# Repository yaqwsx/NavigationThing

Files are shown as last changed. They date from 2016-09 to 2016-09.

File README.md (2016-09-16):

# NavigationThing

The thing, which will safely guide you through darkness. A prop used during
[K-SCUK 2016](http://kscuk.fi.muni.cz/) night game.

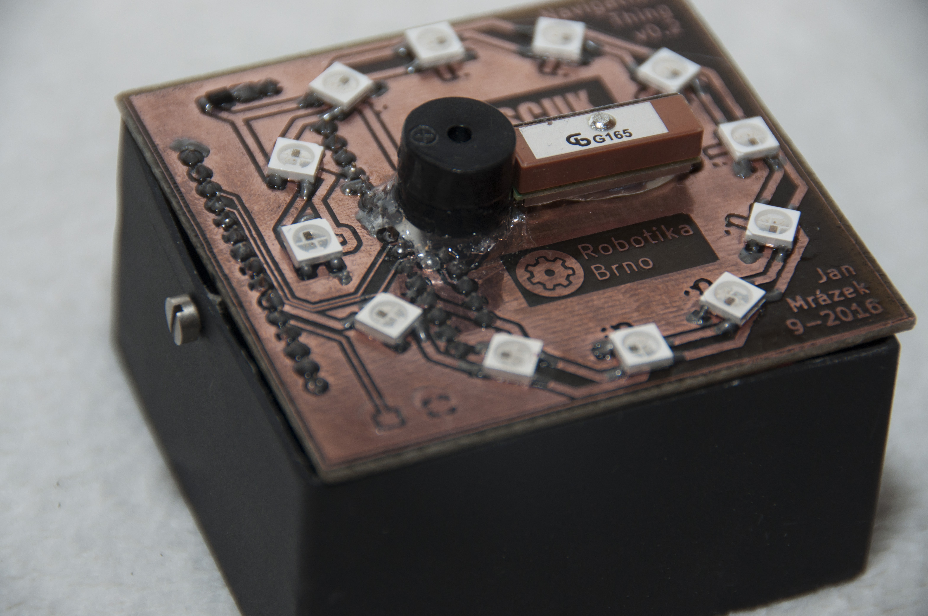
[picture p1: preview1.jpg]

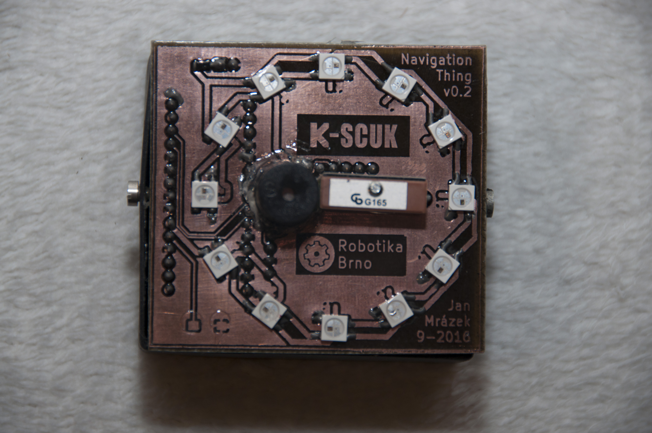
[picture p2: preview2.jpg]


# What does it do?

NavigationThing features an electronic compass and a GPS receiver, which are
used for navigation of a user through a series of waypoints. Distance to the
next waypoint is indicated via beeping, which adds a mysterious feeling. Closer
the user is, the faster the box beeps. NavigationThing is powered by 4 AA
batteries.

# How to use it?

The navigation thing is ready out of box. When you power it for the first time,
the unit beeps, goes black for 3 seconds and then the unit enters compass
calibration mode, which is indited via purple flashing. **It is necessary to
rotate the unit on a flat surface until it stops flashing.** After initial setup,
the unit starts normal operation.

During normal operation, the thing shows either electronic compass or flashes
red. Red flashing indicates missing GPS fix. The thing remembers progress in
EEPROM, so user can safely remove batteries in the middle of operation and
insert them back again. To reset the unit, simply short two pads in the left-
bottom corner of PCB during power-up. Then restart the unit.

To change waypoints, change `waypoints` array in the firmware source code. When
user enters a waypoint, an user supplied callback function is called.

# Repository Structure

The repository is organized as follow:

- `NavigationThing` contains the unit's firmware. The firmware is written in
  Arduino to keep things simple.

- `NavigationThingHwTest` contains testing firmware, which tests the PCB - LEDs
  and peripherals communication.

- `hw` contains schematics and PCBs in KiCAD

I am sorry, there are no CAD files for the box.

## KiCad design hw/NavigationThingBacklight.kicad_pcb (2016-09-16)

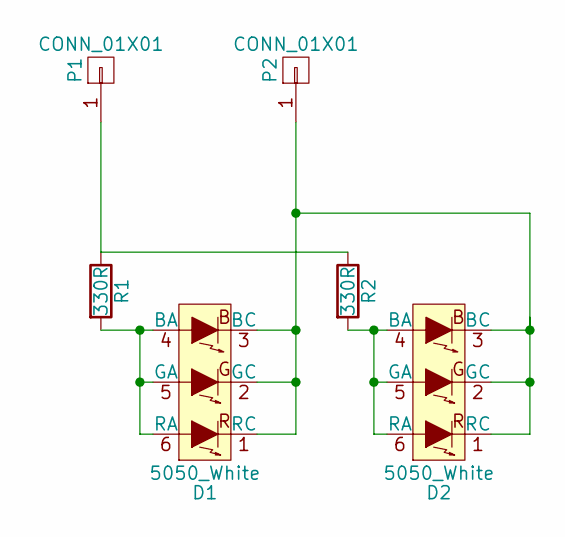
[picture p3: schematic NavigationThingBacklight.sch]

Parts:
D1, D2: 5050_White; LED_RGB_PLLC-6
P1, P2: CONN_01X01; SolderWirePad_single_SMD_5x10mm
R1, R2: 330R; R_0603_HandSoldering

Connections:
unnamed: D1.1 (RC), D1.2 (GC), D1.3 (BC), D2.1 (RC), D2.2 (GC), D2.3 (BC), P2.1
unnamed: D1.4 (BA), D1.5 (GA), D1.6 (RA), R1.2
unnamed: D2.4 (BA), D2.5 (GA), D2.6 (RA), R2.2
unnamed: P1.1, R1.1, R2.1

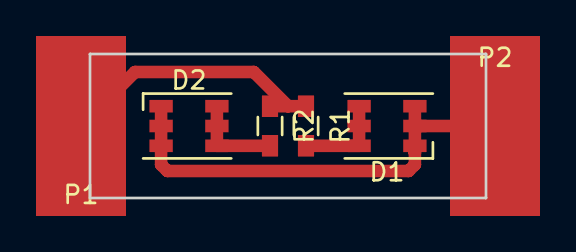
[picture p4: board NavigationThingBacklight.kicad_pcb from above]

Board: 2 copper layers, 22.0 x 8.0 mm, 6 parts (0 on the bottom side), 4 nets.

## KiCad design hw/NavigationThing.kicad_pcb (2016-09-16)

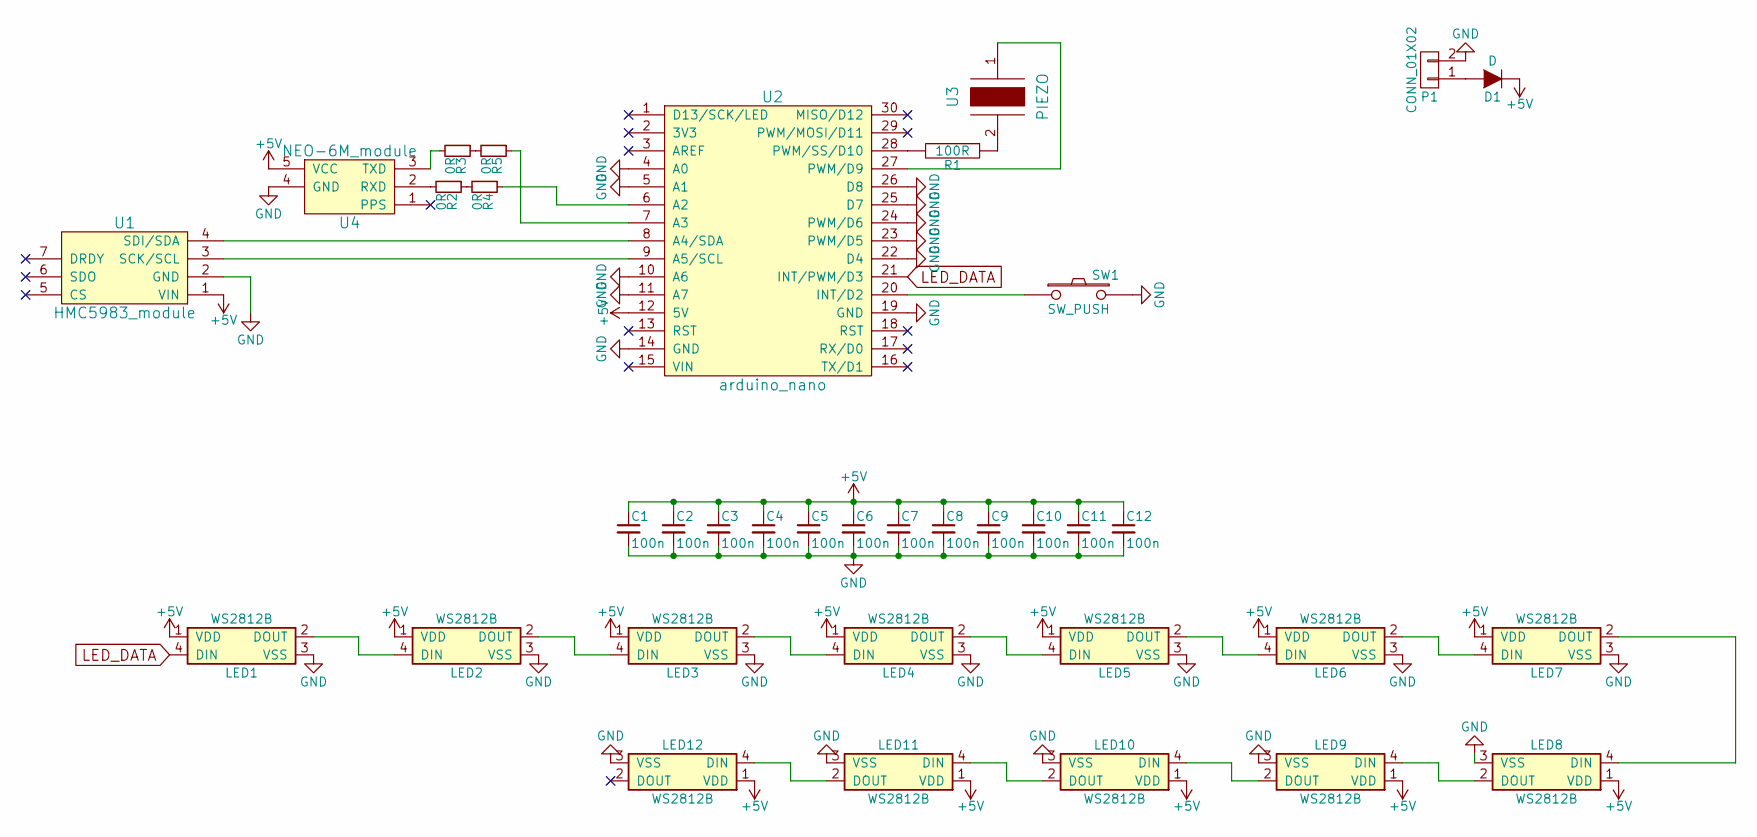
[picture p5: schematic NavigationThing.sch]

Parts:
C1, C2, C3, C4, C5, C6, C7, C8, C9, C10, C11, C12: 100n; C_0603
D1: D; SOD-323
LED1, LED2, LED3, LED4, LED5, LED6, LED7, LED8, LED9, LED10, LED11, LED12: WS2812B; LED_WS2812B-PLCC4
P1: CONN_01X02; Pin_Header_Straight_1x02
R1: 100R; R_0603_HandSoldering
R2, R3, R4, R5: 0R; R_0603_HandSoldering
SW1: SW_PUSH; SW_SPST_EVQPE1
U1: HMC5983_module
U2: arduino_nano
U3: PIEZO; piezo_12
U4: NEO-6M_module

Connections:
+5V: C1.1, C2.1, C3.1, C4.1, C5.1, C6.1, C7.1, C8.1, C9.1, C10.1, C11.1, C12.1, D1.1 (K), LED1.1 (VDD), LED2.1 (VDD), LED3.1 (VDD), LED4.1 (VDD), LED5.1 (VDD), LED6.1 (VDD), LED7.1 (VDD), LED8.1 (VDD), LED9.1 (VDD), LED10.1 (VDD), LED11.1 (VDD), LED12.1 (VDD), U1.1 (VIN), U2.12 (5V), U4.5 (VCC)
GND: C1.2, C2.2, C3.2, C4.2, C5.2, C6.2, C7.2, C8.2, C9.2, C10.2, C11.2, C12.2, LED1.3 (VSS), LED2.3 (VSS), LED3.3 (VSS), LED4.3 (VSS), LED5.3 (VSS), LED6.3 (VSS), LED7.3 (VSS), LED8.3 (VSS), LED9.3 (VSS), LED10.3 (VSS), LED11.3 (VSS), LED12.3 (VSS), P1.2, SW1.2, U1.2 (GND), U2.4 (A0), U2.5 (A1), U2.10 (A6), U2.11 (A7), U2.14 (GND), U2.19 (GND), U2.22 (D4), U2.23 (PWM/D5), U2.24 (PWM/D6), U2.25 (D7), U2.26 (D8), U4.4 (GND)
LED_DATA: LED1.4 (DIN), U2.21 (INT/PWM/D3)
unnamed: D1.2 (A), P1.1
unnamed: LED1.2 (DOUT), LED2.4 (DIN)
unnamed: LED2.2 (DOUT), LED3.4 (DIN)
unnamed: LED3.2 (DOUT), LED4.4 (DIN)
unnamed: LED4.2 (DOUT), LED5.4 (DIN)
unnamed: LED5.2 (DOUT), LED6.4 (DIN)
unnamed: LED6.2 (DOUT), LED7.4 (DIN)
unnamed: LED7.2 (DOUT), LED8.4 (DIN)
unnamed: LED8.2 (DOUT), LED9.4 (DIN)
unnamed: LED10.2 (DOUT), LED11.4 (DIN)
unnamed: LED9.2 (DOUT), LED10.4 (DIN)
unnamed: LED11.2 (DOUT), LED12.4 (DIN)
unnamed: R1.1, U3.2
unnamed: R1.2, U2.28 (PWM/SS/D10)
unnamed: R2.1, R4.2
unnamed: R2.2, U4.2 (RXD)
unnamed: R3.1, R5.2
unnamed: R3.2, U4.3 (TXD)
unnamed: R4.1, U2.6 (A2)
unnamed: R5.1, U2.7 (A3)
unnamed: SW1.1, U2.20 (INT/D2)
unnamed: U1.3 (SCK/SCL), U2.9 (A5/SCL)
unnamed: U1.4 (SDI/SDA), U2.8 (A4/SDA)
unnamed: U2.27 (PWM/D9), U3.1

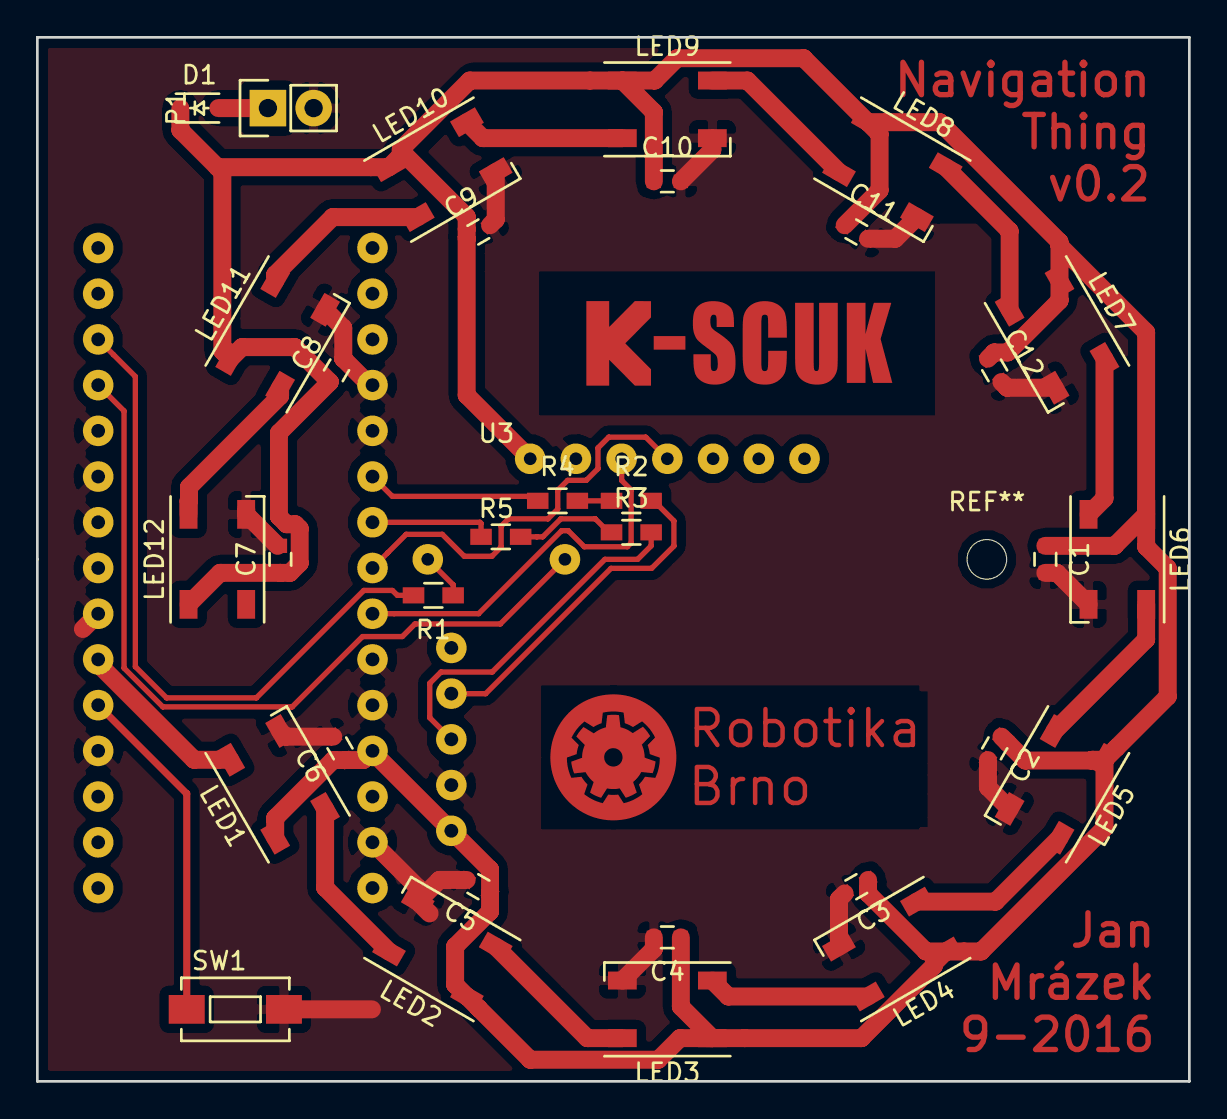
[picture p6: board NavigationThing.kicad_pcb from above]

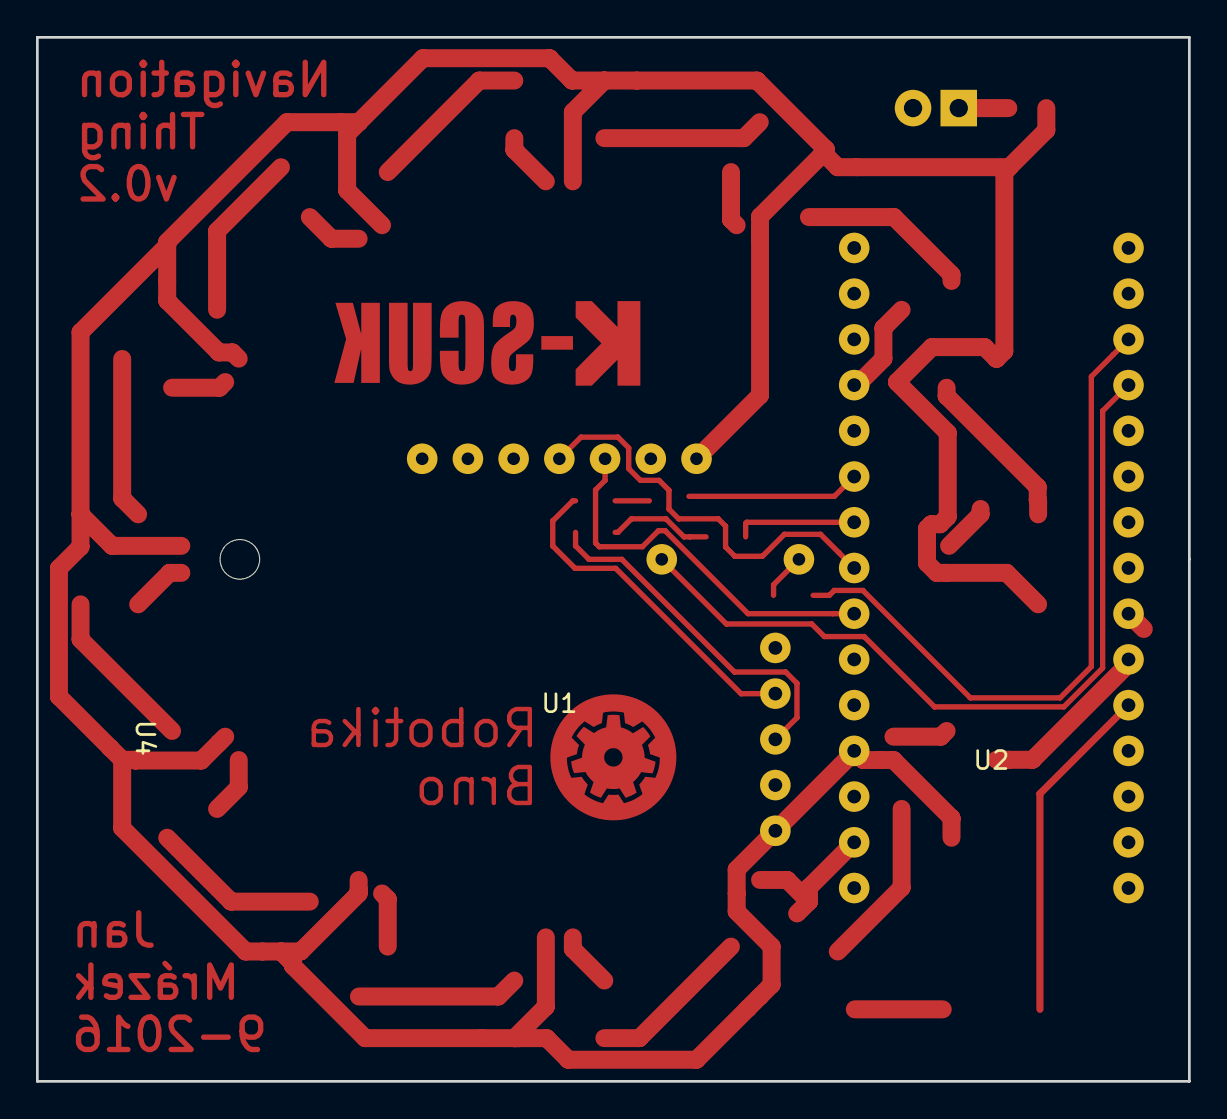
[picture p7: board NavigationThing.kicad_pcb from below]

Board: 2 copper layers, 64.0 x 58.0 mm, 38 parts (3 on the bottom side), 27 nets.

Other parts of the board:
svg2mod: G***; robotarna_cu_7mm
svg2mod#2: G***; kscuk_cu_17mm

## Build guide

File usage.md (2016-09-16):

# K-SCUK Terrain Training Kit

**Před prvním použitím čtěte celou tuto příbalovou informaci.**

Vezměte si prosím s sebou právě jednu tuto příbalovou informaci a právě jednu
jednotku K-SCUK Terrain Training Kitu (KTTK). KTTK vás bude provázet cvičením.
Opatrujte ji prosím jako své vlastní oko ve své vlastní hlavě. Záleží na tom
totiž vaše zdárné dokončení cvičení (a mimo jiné i vaše přežití v místním
nehostinném prostředí).

## Spuštění KTTK

Vložte 4 tužkové baterie do spodu KTTK dle piktogramů v držáku. KTTK zapípá, na
chvíli bude zhasnutá. Postavte ji ihned na rovnou podložku a vyčkejte, až začne
fialově blikat. Poté ihned začněte KTTK otáček kolem dokola (rychlostí cca
otáčka za 3 sekundy) po rovném povrchu dokud nepřestane blikat. Tím provedete
kalibraci kompasu. Po úspěšné kalibraci se KTTK červeně rozbliká. Dokud KTTK
červeně bliká, nepohybujte se a vyčkejte na určení polohy. Pokud KTTK bliká
jinou barvou, kontaktujte prosím výrobce nebo distributora. **Po spuštění
jednotky z ní za žádných okolností nevyjímejte baterie!** Hrozí znefunkčnění
jednotky (a následné nedokončení cvičení). Pokud jednotka někdy v průběhu
cvičení začne červeně blikat, zajistěte jí dobrý výhled na oblohu. Pokud tento
stav přetrvává déle než 15 minut, kontaktujte prosím výrobce nebo distributora.

## Co s KTTK Vlastě dělat a nedělat?

Dělat: Nechat se navigovat.\
Nedělat: Cokoliv, co by udělalo výrobce a distributora nešťastného.

## Jak jednotku ovládat?

Nijak. Po určení polohy začne KTTK pípat a zobrazovat elektronický kompas. Ten
vás postupně naviguje za vašimi cíli. Čím blíže jste cíle, tím rychleji KTTK
pípá. Jakmile se dostatečně přiblížíte cíli, KTTK vás upozorní. Pokud vás KTTK
upozorní postupně vzrůstající melodií, hledejte na místě zadání úkolu. Jinak
pokračujte na další stanoviště. Povšimněte si, že KTTK změní barvu kompasu při
navigaci na další cíl.

## Poznámky na závěr

**Během pohybu využívejte cest! Přímá cesta za kompasem může vést k záhubě.**

**Pro správnou funkci kompasu je třeba jej držet dále od magnetických předmětů a
je nutné jej držet vodorovně. V opačném případě může kompas poskytovat
zavádějící informace. Pokud kompas detekuje jednu z těchto událostí, začne
blikat. Zkuste se zastavit, držet krabičku vodorovně a nechat kompas ustálit.**

## FAQ

Q: Co je to KTTK?\
A: Jak uvádí první odstavec: K-SCUK Terrain Training Kit.

Q: Má KTTK nějaké vedlejší účinky?\
A: Ano, má. Vypaluje barevné body do sítnice a je silně návyková.

Q: Vypěstoval jsem si na KTTK závislost, kde si můžu pořídit vlastní?\
A: Je nám líto, bohužel KTTK jsou určeny pouze pro účely K-SCUKu. V této situaci
také doporučujeme podstoupit psychiatrickou léčbu.

Q: KTTK je cool, kde si ji můžu koupit?\
A: Je nám líto, bohužel KTTK jsou určeny pouze pro účely K-SCUKu.

Q: Z KTTK mi vypadly baterky. Nic nefunguje, co dělat?\
A: Čekat na smrt, byli jste varováni...

Q: KTTK vypadá mrtvě. Co mám dělat?\
A: Vy jste KTTK rozbili! Můžete se buď v klidu posadit a počkat na smrt v této
nehostinné krajině anebo můžete zkusit kontaktovat distributora nebo výrobce KTTK.

Q: Jak kontaktuji distributora KTTK?\
A: Telefonicky.

Q: Na jakém telefonním čísle můžu kontaktovat distributora KTTK?\
A: X.

Q: Jak kontaktuji výrobce KTTK?\
A: Obdobně jako distributora KTTK.

Q: Na jakém telefonním čísle můžu kontaktovat výrobce KTTK?\
A: Y.

Q: Mám kontaktovat distributora nebo výrobce. Kdo je preferovanější?\
A: Výrobce KTTK.

Q: Co mám dělat, když se nemůžu ani na jedno číslo dovolat?\
A: Opakovat operaci za 5 minut.

Q: Co mám dělat, když nemám signál?\
A: Můžete se buď v klidu posadit a počkat na smrt v této nehostinné krajině
anebo pokud chcete přežít, otevřete nápovědu $\alpha$.

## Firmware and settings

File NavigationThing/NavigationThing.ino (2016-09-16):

#include <Wire.h>
#include <EEPROM.h>
#include <FastLED.h>
#include <SoftwareSerial.h>
#include <TinyGPS++.h>
#include <toneAC.h>
#include "misc.h"

class Coord {
public:
  Coord(double lat = 0, double lon = 0)
    : _lat(lat), _lon(lon)
  {}

  Coord(TinyGPSLocation l)
    : _lat(l.lat()), _lon(l.lng())
  {}

  double dist(const Coord& other) {
    return TinyGPSPlus::distanceBetween(_lat, _lon, other._lat, other._lon);
  }

  void dump() {
    Serial.print(_lat, 10);
    Serial.print(" ");
    Serial.println(_lon, 10);
  }

  double azimuth(const Coord& other) {
     return TinyGPSPlus::courseTo(_lat, _lon, other._lat, other._lon);
  }

private:
  double _lat, _lon;
};

template <class S>
class Gps {
public:
  template <class... Args>
  Gps(Args...args) :_ser(args...) {}

  void begin() {
    delay(1000);
    _ser.begin(9600);
    // Output TMCGGA
    _ser.println("$PMTK314,0,1,0,1,0,0,0,0,0,0,0,0,0,0,0,0,0,0,0*28");
    // Update 1 Hz
    _ser.println("$PMTK220,1000*1F");
    // Antenna update
    _ser.println("$PGCMD,33,1*6C");
  }

  bool update() {
    while(_ser.available()) {
      char c = _ser.read();
      //Serial.print(c);
      if (_gps.encode(c)) {
        return true;
      }
    }
    return false;
  }

  bool fix() {
    return _gps.location.age() < 3000;
  }

  Coord pos() {
    return {_gps.location};
  }
private:
  S _ser;
  TinyGPSPlus _gps;
};

template <int SAMPLE_COUNT>
class CompassImp {
  public:
    CompassImp(int compensation, CRGB* leds, int count)
      : _comp(compensation), _leds(leds), _count(count), _color(CRGB::Red), _idx(0)
    {
      EEPROM.get(0, _x_comp);
      EEPROM.get(4, _y_comp);

      for (int i = 0; i != SAMPLE_COUNT; i++)
        _headings[i] = 0;
    }

    void calibrate(CRGB color = {0, 0, 128}) {
      for(int i = 4; i != 0; i--)
        toneAC(i * 1000, 10, 200);
      begin();
      delay(3500);
      unsigned long long t = millis();
      int x_max = 0, x_min = 0;
      int y_max = 0, y_min = 0;
      while(millis() - t < 10000) {
        Wire.beginTransmission(0x1E);
        Wire.write(0x03);
        Wire.endTransmission();
  
        int x = 0, y = 0, z = 0;
        Wire.requestFrom(0x1E, 6);
        if(6<=Wire.available()){
          x = Wire.read()<<8; //X msb
          x |= Wire.read(); //X lsb
          z = Wire.read()<<8; //Z msb
          z |= Wire.read(); //Z lsb
          y = Wire.read()<<8; //Y msb
          y |= Wire.read(); //Y lsb
        }

        if (x_min == 0 || x_min > x)
          x_min = x;
        if (x_max == 0 || x_max < x)
          x_max = x;

        if (y_min == 0 || y_min > y)
          y_min = y;
        if (y_max == 0 || y_max < y)
          y_max = y;
        
        for (int i = 0; i != _count; i++)
          _leds[i] = ((millis() - t) % 400) < 200 ? CRGB::Black : color;
        FastLED.show();
      }

      Serial.print("X: "); Serial.print(x_min);
      Serial.print(", "); Serial.println(x_max);
      Serial.print("Y: "); Serial.print(y_min);
      Serial.print(", "); Serial.println(y_max);

      _x_comp = -(x_min + x_max) / 2;
      _y_comp = -(y_min + y_max) / 2;
      toneAC(4000, 10, 100);

      EEPROM.put(0, _x_comp);
      EEPROM.put(4, _y_comp);

      Serial.print("Comp: "); Serial.print(_x_comp);
      Serial.print(", "); Serial.println(_y_comp);
      
      delay(1000);
      toneAC(4000, 10, 500);

      for (int i = 0; i != _count; i++)
        _leds[i] = CRGB::Black;
      FastLED.show();
    }

    void begin() {
      Wire.begin();
      Wire.beginTransmission(0x1E);
      Wire.write(0x02);
      Wire.write(0x00);
      Wire.endTransmission();
    }

    void set_color(CRGB color) {
      _color = color;
    }

    float get_heading() {
      Wire.beginTransmission(0x1E);
      Wire.write(0x03);
      Wire.endTransmission();

      int x = 0, y = 0, z = 0;
      Wire.requestFrom(0x1E, 6);
      if(6<=Wire.available()){
        x = Wire.read()<<8; //X msb
        x |= Wire.read(); //X lsb
        z = Wire.read()<<8; //Z msb
        z |= Wire.read(); //Z lsb
        y = Wire.read()<<8; //Y msb
        y |= Wire.read(); //Y lsb
      }

      x += _x_comp;
      y += _y_comp;

      _len = sqrt((long long)x*x + (long long)y*y);
      // Serial.print("Length: "); Serial.println(_len);

      float head = atan2((float)y, (float)x) * 180 / M_PI + _comp;
      while (head < 0)
        head += 360;
      while (head > 360)
        head -= 360;

      _idx++;
      if (_idx == SAMPLE_COUNT)
        _idx = 0;
      _headings[_idx % SAMPLE_COUNT] = head;

      float sum = 0;
      for (int i = 0; i != SAMPLE_COUNT; i++)
        sum += _headings[i];

      return head;
      return sum / SAMPLE_COUNT;
    }

    void show(int angle) {
      float heading = 360 * 3 - get_heading() - angle;
      float led = (heading * _count + heading / (2 * _count)) / 360;
      int led_pos = led;
      for (int i = 0; i != _count; i++)
        _leds[i] = CRGB::Black;

      if (_len > 140 && _len < 420 || millis() % 400 < 200)
        _leds[led_pos % _count] = _color;

      FastLED.show();
    }

  private:
    int _comp, _x_comp, _y_comp;
    int _len;
    CRGB* _leds;
    int _count;
    CRGB _color;
    float _headings[SAMPLE_COUNT];
    int _idx;
};

using Compass = CompassImp<10>;

template <class GPS>
class Navigation {
public:
  Navigation(GPS& gps, Compass& comp, CRGB* leds, int count)
    : _gps(gps), _comp(comp), _leds(leds), _count(count), _led_state(false), _last_toggle_time(millis()) {}

  void set_target(Coord c) {
    _target = c;
  }

  Coord wait_for_fix() {
    while(true) {
      if (_gps.update()) {
        Serial.print("Fix: "); Serial.println((int)_gps.fix());
        _gps.pos().dump();
  
        if (_gps.fix())
          return _gps.pos();
        else
          toggle_warning();
      }
    }
  }

  void update() {
    if (_gps.update()) {
      Serial.print("Fix: "); Serial.println((int)_gps.fix());
      _gps.pos().dump();

      if (_gps.fix()) {
        Serial.print("Distance: "); Serial.println(_gps.pos().dist(_target));
        Serial.print("Azimuth:  "); Serial.println(_gps.pos().azimuth(_target));
      }

    }

    if (_gps.fix()) {
      hadle_beep(_gps.pos().dist(_target));
    }

    if (_gps.fix() && millis() - _last_comp_update > 200) {
      _last_comp_update = millis();
      _comp.show(_gps.pos().azimuth(_target));
    }
    
    if (!_gps.fix()) {
      toggle_warning();
    }
  }

  bool are_we_there() {
    if (!_gps.fix())
      return false;
    return _gps.pos().dist(_target) < 30;
  }

  void toggle_warning() {
    if (millis() - _last_toggle_time < 400)
      return;
    _last_toggle_time = millis();
    CRGB c = _led_state ? CRGB(16, 0, 0) : CRGB(0, 0, 0);
    _led_state = !_led_state;
    for (int i = 0; i != _count; i++)
      _leds[i] = c;

    FastLED.show();
  }

  void hadle_beep(int d) {
    if (d > 1000)
      _next_beep = 2500;
    else {
      d -= 10;
      if (d < 10)
        d = 10;
      _next_beep = 33 * sqrt(d) + 20;
    }

    if (millis() - _last_beep > _next_beep) {
      _last_beep = millis();
      toneAC(3000, 10, 20);
    }
  }
  
private:
  GPS& _gps;
  Compass& _comp;
  unsigned long long _last_comp_update;
  CRGB* _leds;
  int _count;

  bool _led_state;
  unsigned long long _last_toggle_time;
  Coord _target;

  unsigned long long _last_beep;
  int _next_beep;
};

struct Waypoint{
  Coord coords;
  CRGB color;
  void (*enter_func)();
};

void basic_enter() {
  for (int j = 0; j != 2; j++) {
    for (int i = 0; i != 7; i++) {
      toneAC(600 * i, 10, 150);
    }
  }
}

const int LED_COUNT = 12;
CRGB leds[LED_COUNT];

void fill_with(CRGB col) {
  for (int i = 0; i != LED_COUNT; i++)
        leds[i] = col;
  FastLED.show();
}

Coord secretTrigger = { 49.1043933, 16.1922400 };
Waypoint secretWaypoint = { {49.1029500, 16.1918000}, {16, 16, 16}, nullptr};

Waypoint waypoints[] = {
  { {49.1036661, 16.1809603}, {16, 0, 0}, basic_enter },
  { {49.1037667, 16.1828667}, {0, 16, 0}, basic_enter },
  { {49.1027272, 16.1816669}, {0, 0, 16}, basic_enter },
  { {49.1036239, 16.1833636}, {0, 16, 0}, basic_enter },
  { {49.1059864, 16.1843600}, {16, 0, 0}, basic_enter }
};
const int wp_count = sizeof(waypoints) / sizeof(Waypoint);

using GpsType = Gps<SoftwareSerial>;
GpsType gps(A3,A2);
Compass compass(200, leds, LED_COUNT);
Navigation<GpsType> nav(gps, compass, leds, LED_COUNT);

int wp_num = 0;

void setup() {
  Serial.begin(115200);
  FastLED.addLeds<WS2812B, 3, GRB>(leds, LED_COUNT);
  fill_with(CRGB::Black);
  
  pinMode(2, INPUT_PULLUP);
  if (digitalRead(2) == LOW) {
    // Reset game position
    wp_num = 0;
    EEPROM.put(8, wp_num);
    int calib = 1;
    EEPROM.put(12, calib);
    // Calibrate compass
    //compass.calibrate();
    for(int i = 0; i != 20; i++) {
      toneAC(i * 400, 10, 20);
    }
    while(true);
  }

  int calib;
  EEPROM.get(12, calib);
  if (calib == 1) {
    compass.calibrate(CRGB(16, 0, 16));
    calib = 0;
    EEPROM.put(12, calib);
  }
  
  toneAC(1000, 10, 100);
  compass.begin();
  gps.begin();

  // Load last game position
  EEPROM.get(8, wp_num);

  delay(500);

  toneAC(1000, 10, 100);
  toneAC(2000, 10, 100);

  delay(200);
  if (waypoints[0].enter_func)
    (*waypoints[0].enter_func)();
}

void final_trap() {
  for (int i = 0; i != 7; i++) {
    int b = 255 * i / 7;
    fill_with(CRGB(b, b, b));
    toneAC(600 * i, 10, 150);
  }

  for (int i = 0; i != 7; i++) {
    int b = 255 * i / 7;
    fill_with(CRGB(b, 0, 0));
    toneAC(7 * 600 - 600 * i, 10, 150);
  }

  for (int i = 0; i != 7; i++) {
    int b = 255 * i / 7;
    fill_with(CRGB(b, 0, 0));
    toneAC(7 * 600 - 600 * i, 10, 150);
  }

  for (int i = 0; i != 7; i++) {
    int b = 255 * i / 7;
    fill_with(CRGB(b, 0, 0));
    toneAC(7 * 600 - 600 * i, 10, 150);
  }
  fill_with(CRGB::Black);
  while(true);
}

bool first = true;
bool special = false;

void loop() {
  if (gps.fix() && first) {
    if (gps.pos().dist(secretTrigger) < 70) {
      special = true;
      // Navigate to secret waypoint
      for (int i = 0; i != 3; i ++) {
        toneAC(500, 10, 200);
        delay(200);
      }
    }
    first = false;
  }
  
  static unsigned long long t = millis();
  Waypoint& wp = waypoints[wp_num];
  nav.set_target(wp.coords);
  compass.set_color(wp.color);
  
  if (special) {
    nav.set_target(secretWaypoint.coords);
    compass.set_color(secretWaypoint.color);
  }
  
  nav.update();
  if (millis() - t > 1000) {
    t = millis();
    Serial.print("Navigation target: "); Serial.print(wp_num);
    Serial.print(": "); wp.coords.dump();
  }
  
  if (nav.are_we_there()) {
    if (special) {
      for(int i = 0; i != 5; i++) {
        toneAC(i*800, 100, 200);
      }
      fill_with(CRGB::Black);
      FastLED.show();
      while(true);
    }
    
    wp_num++;
    if (wp_num == wp_count) {
      final_trap();
    }
    else {
      EEPROM.put(8, wp_num);
      wp = waypoints[wp_num];
      if (wp.enter_func) {
        (*wp.enter_func)();
      }
    }
  }
}

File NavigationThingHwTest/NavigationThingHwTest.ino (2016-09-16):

#include <FastLED.h>
#include <Wire.h>
#include <toneAC.h>
#include <SoftwareSerial.h>

const int LED_COUNT = 12;
CRGB leds[LED_COUNT];


void setup() {
  FastLED.addLeds<WS2812B, 3, GRB>(leds, LED_COUNT);
  toneAC(1000, 10, 100);
  toneAC(2000, 10, 100);
  Serial.begin(115200);
  Serial.println("Initialized");

  test_led();
  test_compass();
  test_gps();

  for (int j = 0; j != 2; j++) {
    for (int i = 0; i != 7; i++) {
      toneAC(600 * i, 10, 150);
    }
  }
}

void test_led() {
  for (int j = 0; j != 2 * LED_COUNT; j++) {
    Serial.print("Testing LED no: ");
    Serial.println(j % LED_COUNT);
    for (int i = 0; i != LED_COUNT; i++)
      leds[i] = CRGB::Black;
    leds[j % LED_COUNT] = CRGB(32, 0, 0);
    FastLED.show();
    toneAC(1000, 10, 100);
    delay(300);
  }
}

void test_compass() {
  Wire.begin();
  Wire.beginTransmission(0x1E);
  Wire.write(0x02);
  Wire.write(0x00);
  Wire.endTransmission();
      
  for (int i = 0; i != 10; i++) { 
    Wire.beginTransmission(0x1E);
    Wire.write(0x03);
    Wire.endTransmission();

    int x, y, z;
    Wire.requestFrom(0x1E, 6);
    if(6<=Wire.available()){
      x = Wire.read()<<8; //X msb
      x |= Wire.read(); //X lsb
      z = Wire.read()<<8; //Z msb
      z |= Wire.read(); //Z lsb
      y = Wire.read()<<8; //Y msb
      y |= Wire.read(); //Y lsb
    }
    Serial.print("Comapass: ");
    Serial.print(x); Serial.print(", ");
    Serial.print(y); Serial.print(", ");
    Serial.println(z);
    for (int j = 0; j != LED_COUNT; j++)
      leds[j] = CRGB(0, (i & 1) ? 16 : 0, 0);
    FastLED.show();
    delay(200);
  }
}

void test_gps() {
  SoftwareSerial s(A3, A2);
  s.begin(9600);
  // Output TMCGGA
  s.println("$PMTK314,0,1,0,1,0,0,0,0,0,0,0,0,0,0,0,0,0,0,0*28");
  // Update 1 Hz
  s.println("$PMTK220,1000*1F");
  // Antenna update
  s.println("$PGCMD,33,1*6C");

  auto t = millis();
  while(millis() - t < 5000) {
    while(s.available()) {
      char c = s.read();
      Serial.print(c);
    }
  }
}

void loop() {

}

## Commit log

2016-09-05 Board version 0.1
    [NavigationThing.kicad_pcb, NavigationThing.sch]
2016-09-05 New board version
    - change GPS pins, as the original ones were purely ADC
    - move piezo a little bit to make space for GPS antenna
    - add hole for GPS antenna
    - change signature to text instead of logo (which does not render in SVG)
    [NavigationThing.kicad_pcb, NavigationThing.sch]
2016-09-16 Small board adjustements
    [NavigationThing.kicad_pcb, NavigationThing.sch]
2016-09-16 Add backlight breakout
    [NavigationThingBacklight.kicad_pcb, NavigationThingBacklight.sch]
